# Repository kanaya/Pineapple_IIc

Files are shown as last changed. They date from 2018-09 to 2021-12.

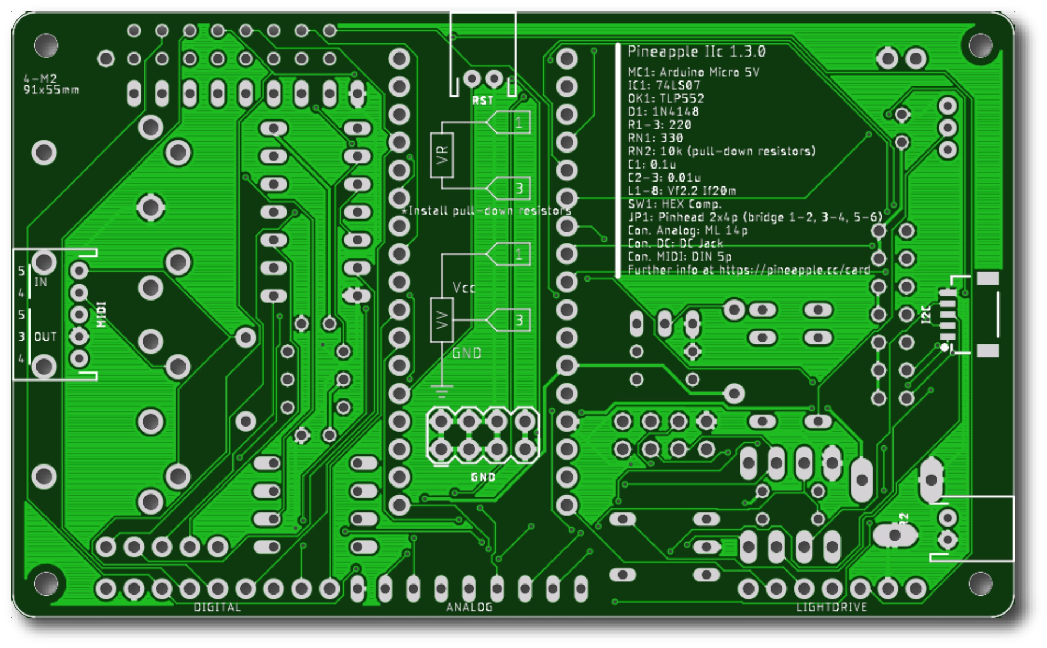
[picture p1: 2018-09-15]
doc/image/Pineapple_IIc_1_3_0_back_shadow_material/4-Pineapple_IIc_1_3_0_back_shadow.png

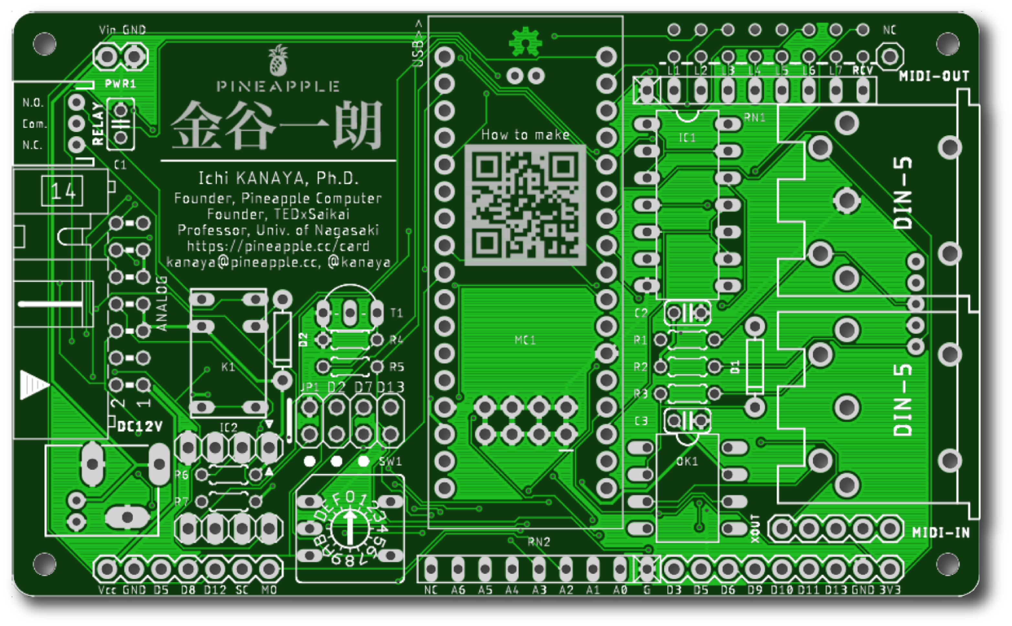
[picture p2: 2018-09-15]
doc/image/Pineapple_IIc_1_3_0_shadow_material/4-Pineapple_IIc_1_3_0_shadow.png

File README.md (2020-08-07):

# Pineapple IIc

Edition 2.0.0 for Pineapple IIc 2.0.0

## Congratulations!

You’ve got the latest version of Pineapple Computer named _Pineapple IIc._ But what is Pineapple Computer? Well, it is a MIDI computer that can convert analog signals to MIDI (digital) signal. Now you may want to ask, I guess, what is it for? The Pineapple Computer is an artist-friendly super-easy-to-use computer! You plug power, sensor, MIDI instrument, and boom! Everything is set up.

## How to set up (Hardware)

### Basics

Install the following components.

| Name | Component | Note |
|---|---|---|
| C1 | 47u | |
| C2 | 10u | |
| C3-6 | 0.1u | |
| D1 | 1N4148 | |
| DC12V | DC Jack | |
| IC1 | 74LS07 | |
| JP2 | Pinheader 1x3p | **Bridge top and mid pins** |
| LED1 | Vf=2.2 If=20m | |
| MC1 | Arduino Micro 5V  | |
| MIDI-OUT | DIN 5p | |
| OK1 | TLP552 | |
| R3-6 | 220 | |
| RN1 | 330 | |
| RN2 | 10k | Using pin sockets is recommended. |
| SV1 | ML 16p | |
| VREG1 | 12V to 5V | |

...To be re-written.

### Non-basic usage

You can drive a relay, I2C devices, and TLC5940 PWM driver by installing some other components on Pineapple IIc. Also you can replace some connectors so that you can use panel mounted connectors and install Pineapple IIc board in a case. For more detail, please read _Extending Pineapple IIc_.

## How to set up (Software)

Install _Pineapple IIc Basic_ sketch to run Pineapple IIc in _Basic_ mode.

## How to play

Connect the following plugs.

* DC---Supply DC 12V to DC Jack connector.
* MIDI---Connect Pineapple IIc's MIDI OUT and your instrument's MIDI IN.
* Sensors---To be written.

## Extending Pineapple IIc

### To use relay

Install the following components as well as _Basic_ components.

| Item | Name | Spec. | # |  Note |
|---|---|---|---|---|
| Transistor  | T1 | 2SC1815 | 1 | |
| Diode | D2 | 1N4148 | 1 | |
| Resistor | R5-6 | 10k | 2 | |
| Relay | K1 | G5V-1 DC5V | 1 | |
| Con. | Relay | PH 3p | 1 | |

Also you need to **bridge 7-8 of JP1.**

### To use I2C

Install the following components as well as _Basic_ components.

| Item | Name | Spec. | # |  Note |
|---|---|---|---|---|
| Signal level converter | IC2  | PCA9517ADP | 1 | Put A-side up, B-side down. |
| Resistor | R7-8 | 6.8k | 2 | |
| Con. | I2C  | SH 5p | 1 | D7 operates at **5V.** |

You need to **un-bridge 1-5, 2-6, 3-7 of JP1.** (D2/SDA and D7 are connected to SW1, and D3PWM/SCL is connected to PWM0 via JP1.)

### To use RST

Install the following components at back side as well as _Basic_ components.

| Item | Name | Spec. | # |  Note |
|---|---|---|---|---|
| Con. | RST (Back) | PH 2p | 1 | |

### To use LIGHTDRIVE

Install the following components as well as _Basic_ components **except for SW1.** Since Arduino's D8 and D12 pins share SW1 connections and LIGHTDRIVE pins, you need to remove SW1.

| Item | Name | Spec. | # |  Note |
|---|---|---|---|---|
| Con. | LIGHTDRIVE | Pinheader 7p | 1 | |

The LIGHTDRIVE pinouts are:

| Lightdrive | Meaning | Arduino Pin |
|---|---|---|
| 1 | Vcc | |
| 2 | GND | |
| 3 | GSCLCK  | D5PWM |
| 4 | BLANK | D8 |
| 5 | XLAT | D12 |
| 6 | SCLCK | SCLK |
| 7 | SIN | MOSI |

### To use extra GND pins

Install the following components at back side as well as _Basic_ components.

| Item | Name | Spec. | # |  Note |
|---|---|---|---|---|
| Con. | GND (back) | Pinheader/socket 2x3p | 1 | |

### To use panel-mounted MIDI connector

Install the following components at back side as well as _Basic_ components.

| Item | Name | Spec. | # |  Note |
|---|---|---|---|---|
| Con. | MIDI (back) | PH 5p | 1 | |

### To use panel-mounted DC Jack

Install one of the following components as well as _Basic_ components.

| Item | Name | Spec. | # |  Note |
|---|---|---|---|---|
| Con. | PWR1 | Pinheader 2p | 1 | |
| Con. | PWR2 (back) | PH 2p | 1 | |

### To use XOUT

XOUT is designed for extra MIDI OUT capability. It is a direct output of Open Collector so that you may want to install 220-ohm resistor for use as MIDI OUT.

Install the following components as well as _Basic_ components.

| Item | Name | Spec. | # |  Note |
|---|---|---|---|---|
| Con. | XOUT | Pinheader 5p | 1 | |

### To use DIGITAL extension

You can hook L1-L7 driver pins by using DIGITAL pins. It also provides +3.3V DC.

Install the following components as well as _Basic_ components.

| Item | Name | Spec. | # |  Note |
|---|---|---|---|---|
| Con. | DIGITL | Pinheader 9p | 1 | |

### To stack multiple cards

To stack multiple cards, you can do one of the following options.

* Use spacer. _Pineapple IIc_ has four M2 holes at each corners ((3, 3), (88, 3) (88, 52), (3, 52) mm).
* Use Pinheaders of Vcc (bottom left), 3V3 (bottom right), _Pogo_ (top right), Vcc (top left) and perhaps GND (next to the Vcc at top left).

## Technical notes

### Arduino Pinout

| Arduino Micro | Signal | JP1 |
|---|---|---|
| RX | MIDI IN | |
| TX | MIDI OUT | |
| D2/SDA | SW0/SDA | 3-4, open to use I2C |
| D3PWM/SCL | PWM0/SCL | |
| D4/A6 | A6 | |
| D5PWM | PWM1 | |
| D6PWM/A7 | PWM2 | |
| D7 | SW1 | 5-6, open to use D7 independently |
| D8/A8 | SW2 | |
| D9PWM/A9 | PWM3 | |
| D10PWM/A10 | PWM4 | |
| D11PWM | PWM5 | |
| D12/A11 | SW3 | |
| D13PWM | PWM6/Relay | 7-8, close to use relay |
| A0-5 | A0-5 | |

### JP1 Pinout

| JP1 | Signal | JP1 | Signal |
|-----|---|-----|---|
| 1 | Level Converter Enable | 2 | GND |
| 3 | D2SDA (SW0/SDA) | 4 | SW0 |
| 5 | D7 (SW1) | 6 | SW1 |
| 7 | D13PWM (PWM6/Relay) | 8 | Relay  |

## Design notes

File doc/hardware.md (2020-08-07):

# Pineapple IIc

_Edition 2.0.1 for Pineapple IIc version 2.0.1-Alpha._

Pineapple IIc is an artist-friendly computer that can convert analog voltage to MIDI signal.

## Overview

Pineapple IIc can take up to 4 analog inputs (0-5V or 0-50mA) and converts them to MIDI signals. An edge of the analog signal (e.g. 0V to 0.1V or 0 to 1mA) causes MIDI Note On signal. Continuous change of the input voltage causes MIDI Control Change, and drop to 0V (or 0mA) causes MIDI Note Off.

Up to 4 analog sensors can be attached to Pineapple IIc. The sensor can be **(1) voltage mode:** analog voltage output (0V when not active), **(2) current mode:** variable resistance (nonconductive when not active).

Table. Sensor Port (16p ML connector)

| Pin | Meaning |
|-----|---|
| S1  | Vcc |
| S2  | GND |
| S3  | GPIO 1 |
| S4  | Analog 1 |
| S5  | Vcc |
| S6  | GND |
| S7  | GPIO 2 |
| S8  | Analog 2 |
| S9  | Vcc |
| S10 | GND |
| S11 | GPIO 3 |
| S12 | Analog 3 |
| S13 | Vcc |
| S14 | GND |
| S15 | GPIO 4 |
| S16 | Analog 4 |

The GPIO 1, 2 and 3 can perform PWM output.

If the pin 3 of MIDI In+ is connected to GND at boot time, Pineapple II switches to _alternative_ mode.

Table. Working mode of Pineapple II

| Aux (m3) | Mode |
|---|---|
| Open | Default mode. Sensor to MIDI Out. |
| GND | Alternative mode. MIDI In to digital out. |

| Pin of Arduino Micro | Meaning |
|---|---|
| D0 | MIDI IN |
| D1 | MIDI OUT |
| D2 | SDA |
| D3 | SCL |
| D4/A6 | Relay |
| D5 | Display 1, SW1 |
| D6/A7 (PWM) | GPIO 1 |
| D7 | Display 2, SW2 |
| D8/A8 | Display 3, SW4 |
| D9/A9 (PWM) | GPIO 2 |
| D10/A10 (PWM) | GPIO 3 |
| D11 | Selector |
| D12/A11 | GPIO 4 |
| D13 | Indicator |
| MOSI | Display 4 |
| MISO | --- |
| SCLK | Display 5 |
| A0 | Analog 1 |
| A1 | Analog 2 |
| A2 | Analog 3 |
| A3 | Analog 4 |
| A4 | SW8 |
| A5 | Thermal sensor, ID |

# Components

| Kind | Symbol | Specification |
|---|---|---|
| Capacitor | C1 | 474 |
| | C2 | 105 |
| | C3 | 104 |
| | C4 | 22u |
| | C5 | 103 |
| | C6 | 103 |
| | C7 | 104 |
| Diode | D1 | 1S3 |
| | D2 | 1S3 |
| | D3 | 1S3 |
| IC | IC1 | 74LS07N |
| Connector | J1 | DC Jack |
| | J2 | DIN 5p |
| | J3 | DIN 5p |
| | J4 | JST PH 2p |
| | J5 | JST PH 3p |
| | J6 | JST PH 5p |
| | J7 | Pinheader 1x5 |
| | J11 | JST SH 4p |
| Jumper | JP1 | Pinheader 2x3 |
| | JP2 | Pinheader 1x3 |
| Relay | K1 | G5V-1 |
| LED | L1 | Any |
| Micro Controller | MC1 | Arduino Micro |
| Optocoupler | OK1 | TLP552 |
| FET | Q11 | BSS138 |
| | Q12 | BSS138 |
| Resistor | R1 | 473 |
| | R2 | 102 |
| | R3 | 221 |
| | R4 | 221 |
| | R5 | 221 |
| | R6 | 221 |
| | R11 | 102 (2012) |
| | R12 | 102 (2012) |
| | R13 | 102 (2012) |
| | R14 | 102 (2012) |
| Resistor Net | RN1 | 10k 4-elements  |
| | RN2 | 4.7k 4-elements |
| Connector ML | SV1 | 16p |
| Transistor | T1 | 2SC1815Y |
| Thermal Sensor | U1 | DS18B20 |
| V. Regulator | V1 | L7805 |

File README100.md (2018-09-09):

# Pineapple IIc 2.0

## Arduino MKR Pinout

| Arduino Micro | Signal | JP1 |
|---|---|---|
| D0~ | PWM0 | |
| D1~ | PWM1 | |
| D2~ | PWM2 | |
| D3~ | PWM3 | |
| D4~ | PWM4 | |
| D5~ | PWM5 | |
| D6~LED | PWM6/Relay | 4-8, close to use relay |
| D7~ | SW1 | 3-7, open to use D7 independently |
| D8~MOSI | SW2 | 1-5, open to use LIGHTDRIVE |
| D9SCK | SW3 | 2-6, open to use LIGHTDRIVE |
| D10~MISO | SW4 | |
| D11SDA | SDA | |
| D12SCL | SCL | |
| D13RX | MIDI IN | |
| D14TX | MIDI OUT | |

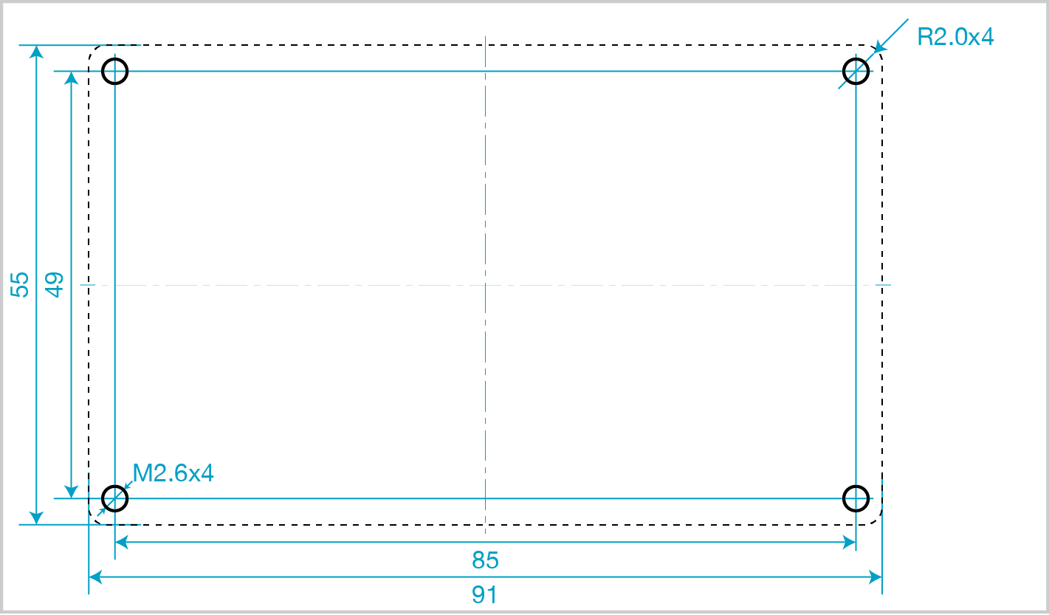
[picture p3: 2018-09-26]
doc/image/Pineapple_IIc_1_5_0_mounting_holes.png

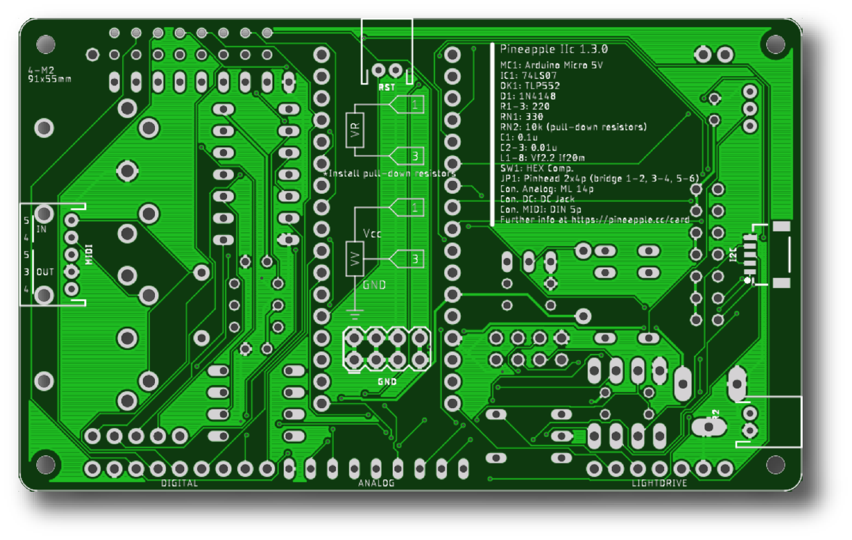
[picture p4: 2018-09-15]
doc/image/Pineapple_IIc_1_3_0_back_half_shadow-QHD.png

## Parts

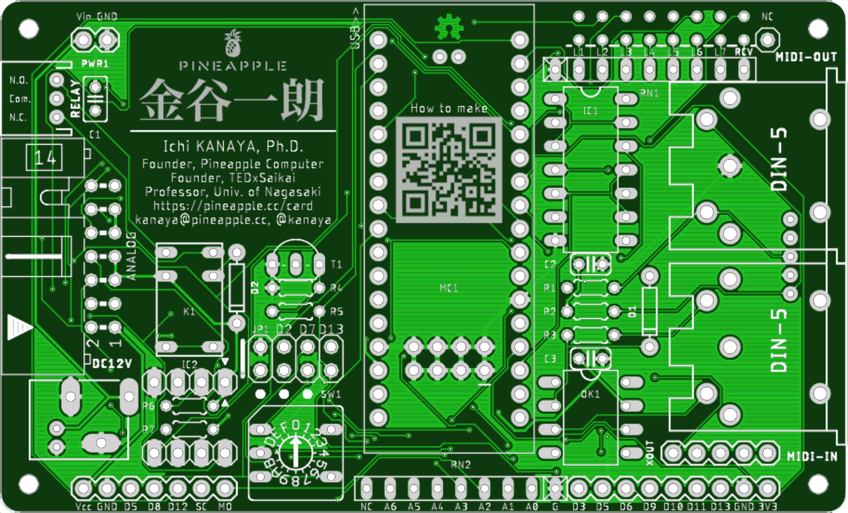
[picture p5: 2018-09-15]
doc/image/Pineapple_IIc_1_3_0_shadow_material/2-Pineapple_IIc_1_3_0.png

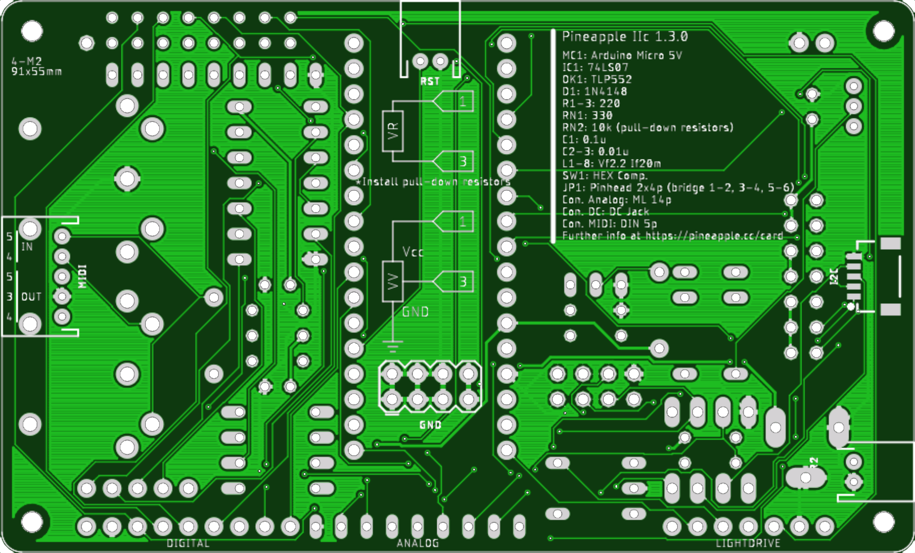
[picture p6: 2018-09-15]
doc/image/Pineapple_IIc_1_3_0_back_shadow_material/2-Pineapple_IIc_1_3_0_back.png

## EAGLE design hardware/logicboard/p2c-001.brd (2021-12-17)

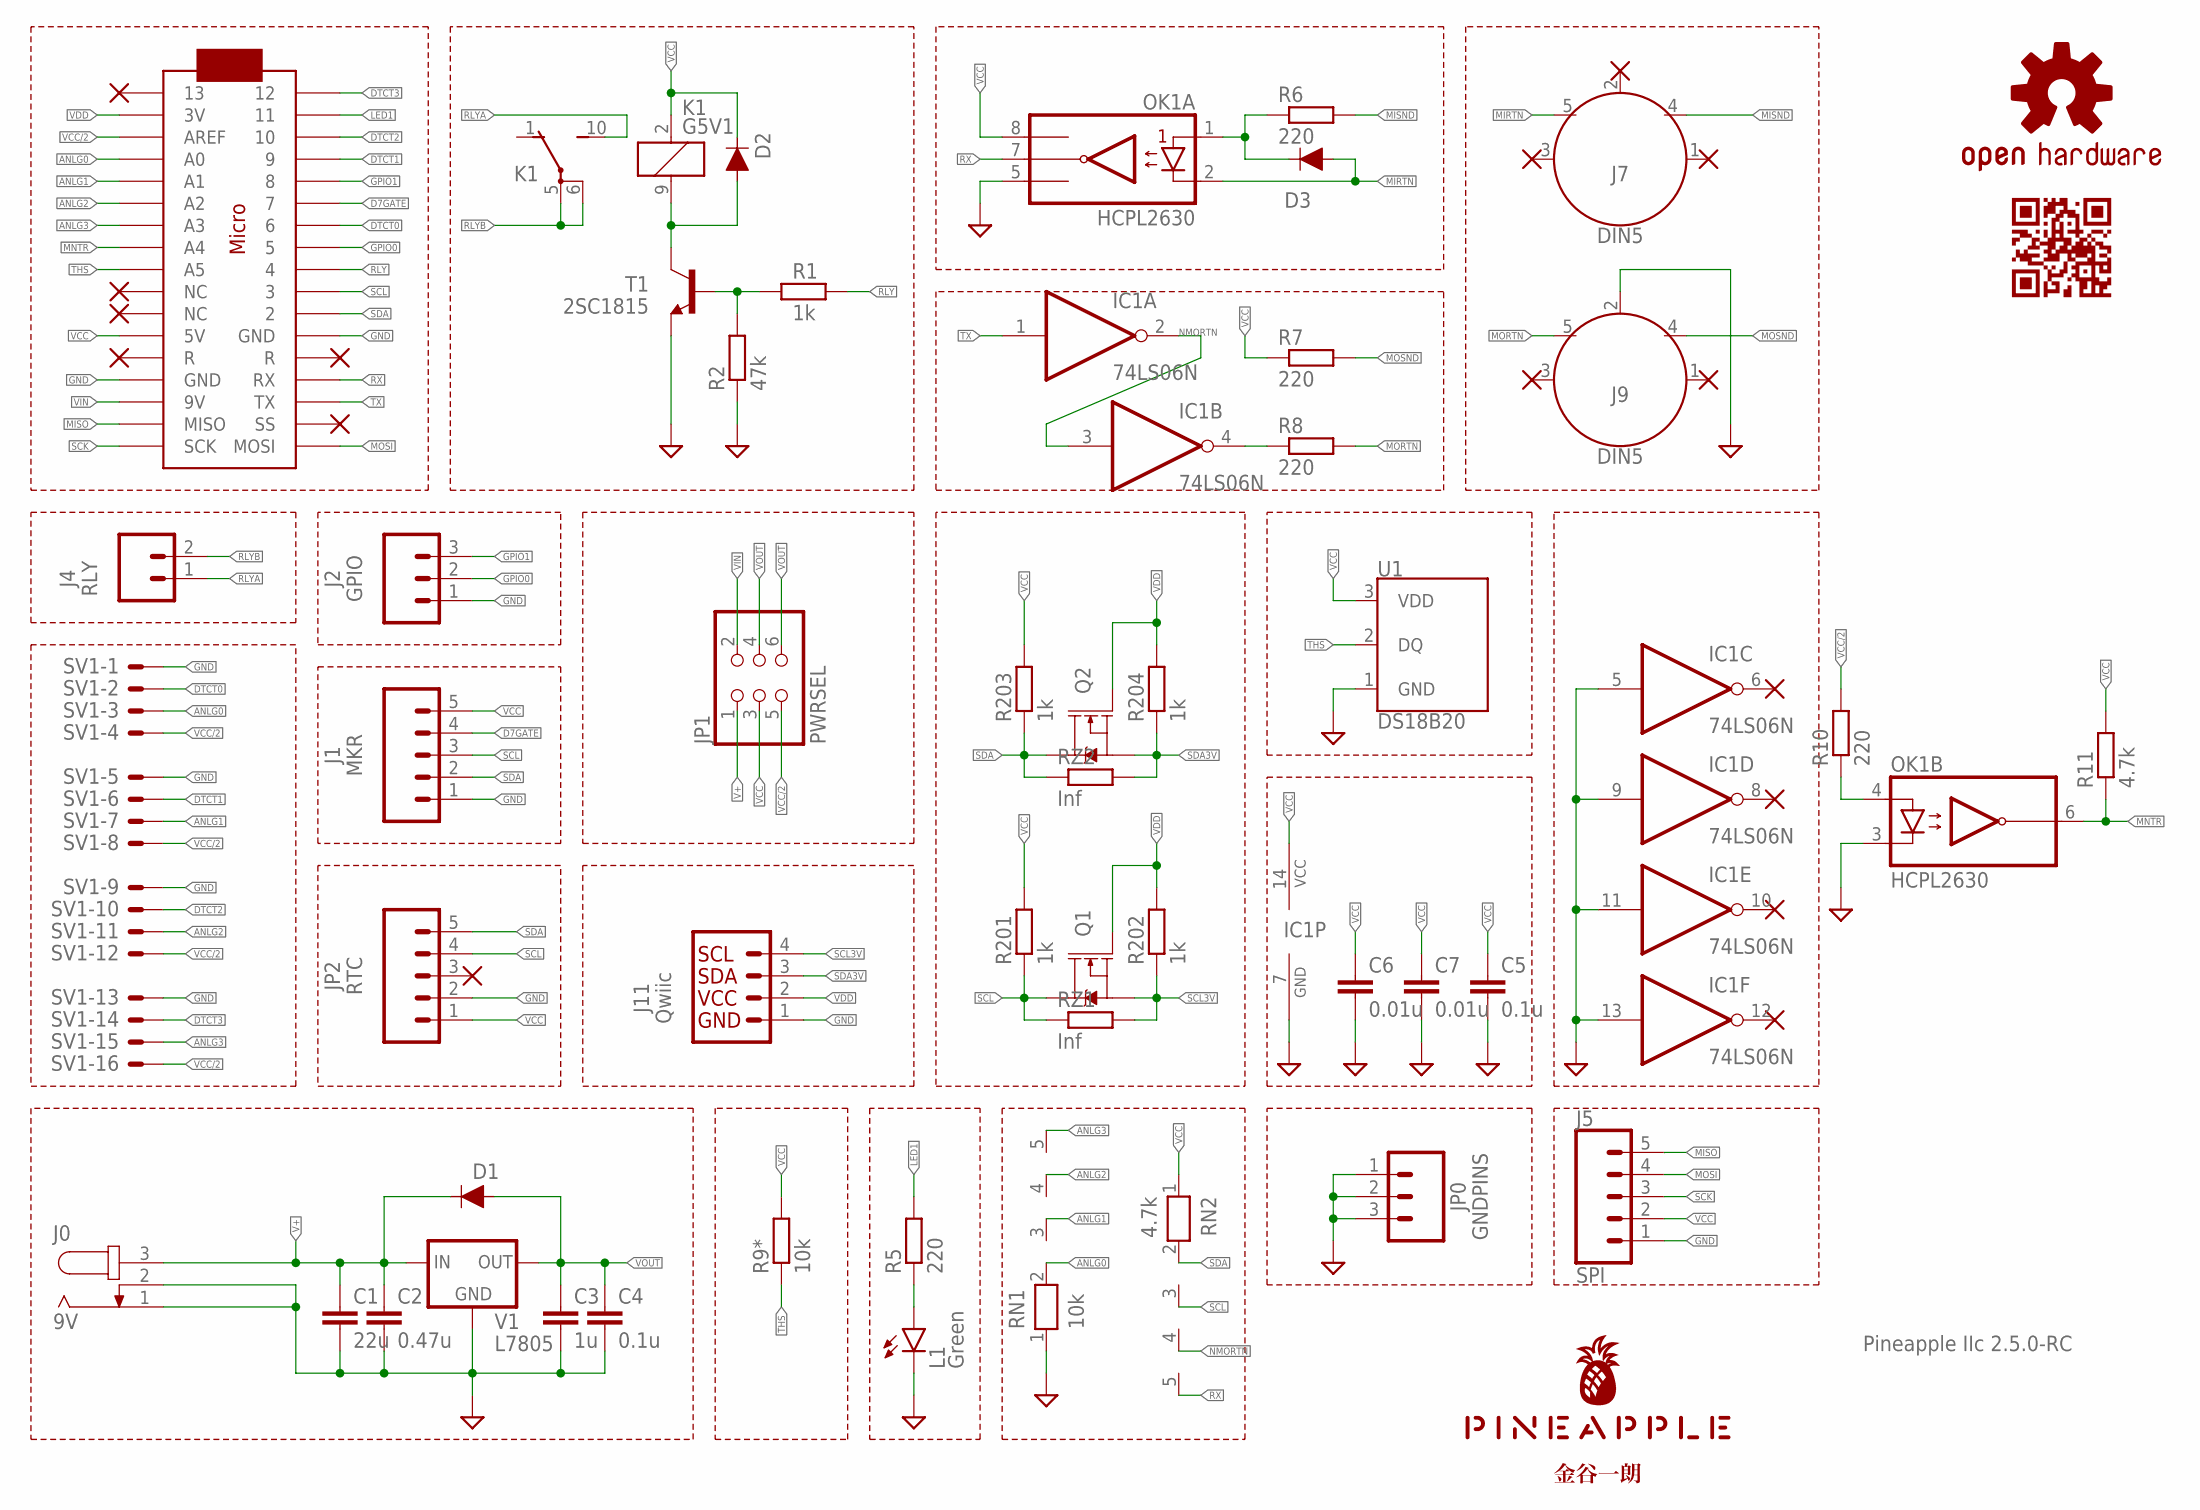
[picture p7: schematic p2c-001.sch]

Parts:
C1: 22u; C025-050X050
C2: 0.47u; C050-024X044
C3: 1u; C050-024X044
C4, C5: 0.1u; C025-024X044
C6, C7: 0.01u; C025-024X044
D1, D2, D3: DIODE-1N4148
IC1: 74LS06N; DIL14
J0: 9V; SPC4077
J1: MKR; JST-5-PTH
J2: GPIO; JST-3-PTH
J4: RLY; JST-2-PTH
J5: SPI; JST-5-PTH-VERT
J7, J9: DIN5; DIN5-RA-PTH
J11: Qwiic; 1X04_1MM_RA
JP0: GNDPINS; 1X03
JP1: PWRSEL; 2X03
JP2: RTC; 1X05
K1: G5V1
L1: Green; LED3MM
LOGO1: OSHW-LOGOS-COPPER; OSHW-LOGO-S_COPPER
OK1: HCPL2630; DIL08
Q1, Q2: 220mA/50V/3.5Ω; SOT23-3
R1: 1k; 0204/5
R2: 47k; 0204/5
R5, R6, R7, R8, R10: 220; 0204/5
R9*: 10k; 0204/5
R11: 4.7k; 0204/5
R201, R202, R203, R204: 1k; R2012
RN1: 10k; RN-5
RN2: 4.7k; RN-5
RZ1, RZ2: Inf; R2012
SV1: ML16LE; ML16L
T1: 2SC1815; TO92-ECB
U1: DS18B20; TO-92-AMMO
U$1: PINEAPPLE450_SILK
U$2: ARDUINOMICRO
U$3: KANAYA768_SILK
U$4: CARDQRCODE450_SILK
V1: L7805; 78XXS

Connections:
ANLG0: RN1.2, SV1.3, U$2.P$31 (A0)
ANLG1: RN1.3, SV1.7, U$2.P$30 (A1)
ANLG2: RN1.4, SV1.11, U$2.P$29 (A2)
ANLG3: RN1.5, SV1.15, U$2.P$28 (A3)
D7GATE: J1.4, U$2.P$6 (7)
DTCT0: SV1.2, U$2.P$7 (6)
DTCT1: SV1.6, U$2.P$4 (9)
DTCT2: SV1.10, U$2.P$3 (10)
DTCT3: SV1.14, U$2.P$1 (12)
GND: C1.2, C2.2, C3.2, C4.2, C5.2, C6.2, C7.2, IC1.5 (I), IC1.7 (GND), IC1.9 (I), IC1.11 (I), IC1.13 (I), J0.1, J0.2, J1.1, J2.1, J5.1, J9.2, J11.1 (GND), JP0.1, JP0.2, JP0.3, JP2.2, L1.K (C), OK1.3 (C2), OK1.5 (GND), R2.1, RN1.1, SV1.1, SV1.5, SV1.9, SV1.13, T1.E, U1.1 (GND), U$2.P$12 (GND), U$2.P$21 (GND), V1.GND
GPIO0: J2.2, U$2.P$8 (5)
GPIO1: J2.3, U$2.P$5 (8)
LED1: R5.2, U$2.P$2 (11)
LED1A: L1.A, R5.1
MIA: D3.C, OK1.1 (A1), R6.1
MIRTN: D3.A, J7.5, OK1.2 (C1)
MISND: J7.4, R6.2
MISO: J5.5, U$2.P$19 (MISO)
MNTR: OK1.6 (VO2), R11.1, U$2.P$27 (A4)
MNTRA: OK1.4 (A2), R10.1
MORTN: J9.5, R8.2
MORTNRAW: IC1.4 (O), R8.1
MOSI: J5.4, U$2.P$17 (MOSI)
MOSND: J9.4, R7.2
NMORTN: IC1.2 (O), IC1.3 (I), RN2.4
RLY: R1.2, U$2.P$9 (4)
RLYA: J4.1, K1.10 (S)
RLYB: J4.2, K1.5, K1.6
RLYC: D2.A, K1.9 (2), T1.C
RLYQ: R1.1, R2.2, T1.B
RX: OK1.7 (VO1), RN2.5, U$2.P$14 (RX)
SCK: J5.3, U$2.P$18 (SCK)
SCL: J1.3, JP2.4, Q1.3 (D), R201.1, RN2.3, RZ1.1, U$2.P$10 (3)
SCL3V: J11.4 (SCL), Q1.2 (S), R202.1, RZ1.2
SDA: J1.2, JP2.5, Q2.3 (D), R203.1, RN2.2, RZ2.1, U$2.P$11 (2)
SDA3V: J11.3 (SDA), Q2.2 (S), R204.1, RZ2.2
THS: R9*.1, U1.2 (DQ), U$2.P$26 (A5)
TX: IC1.1 (I), U$2.P$15 (TX)
V+: C1.1, C2.1, D1.C, J0.3, JP1.1, V1.IN
VCC: C5.1, C6.1, C7.1, D2.C, IC1.14 (VCC), J1.5, J5.2, JP1.3, JP2.1, K1.2 (1), OK1.8 (VCC), R7.1, R9*.2, R11.2, R201.2, R203.2, RN2.1, U1.3 (VDD), U$2.P$23 (5V)
VCC/2: JP1.5, R10.2, SV1.4, SV1.8, SV1.12, SV1.16, U$2.P$32 (AREF)
VDD: J11.2 (VCC), Q1.1 (G), Q2.1 (G), R202.2, R204.2, U$2.P$33 (3V)
VIN: JP1.2, U$2.P$20 (9V)
VOUT: C3.1, C4.1, D1.A, JP1.4, JP1.6, V1.OUT

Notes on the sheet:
Pineapple IIc 2.5.0-RC

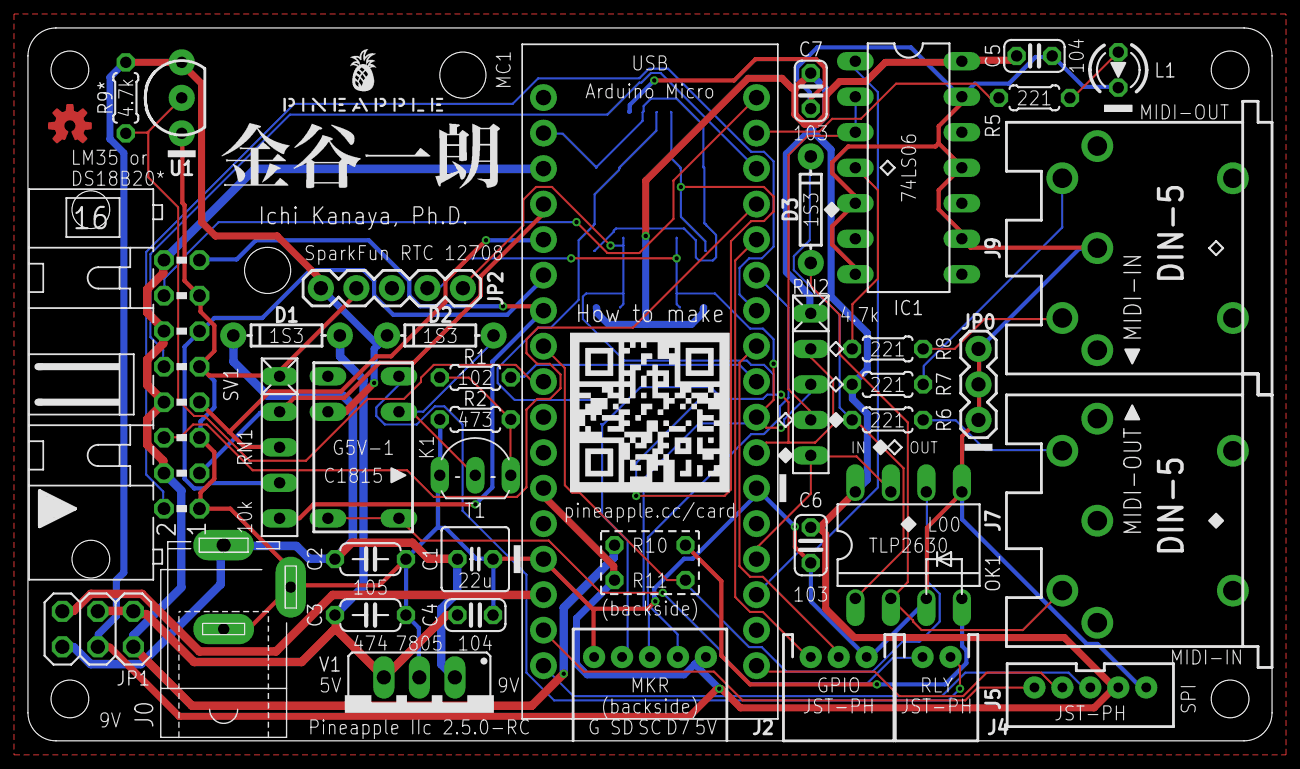
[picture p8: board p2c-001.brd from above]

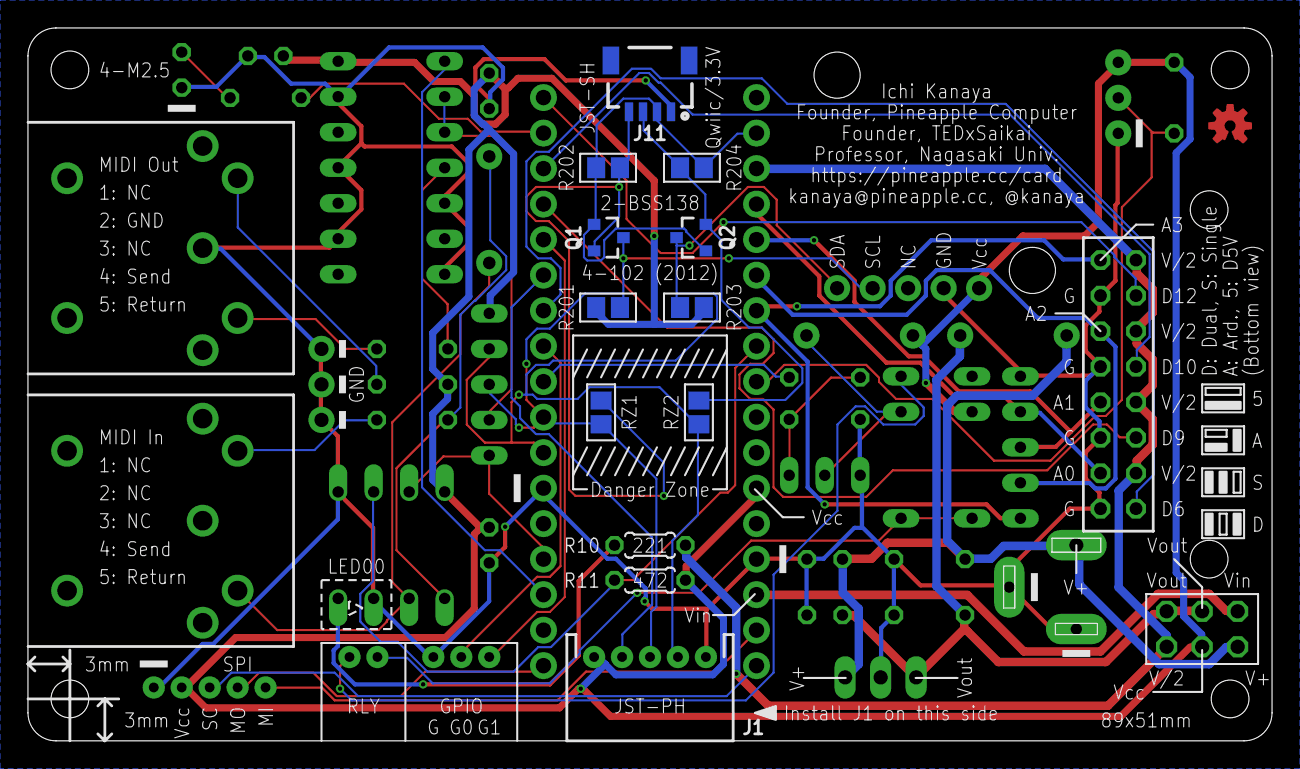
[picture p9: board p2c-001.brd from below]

Board: 2 copper layers, 89.0 x 51.0 mm, 55 parts (12 on the bottom side), 44 nets.

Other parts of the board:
U$5, U$6: STAND-OFF

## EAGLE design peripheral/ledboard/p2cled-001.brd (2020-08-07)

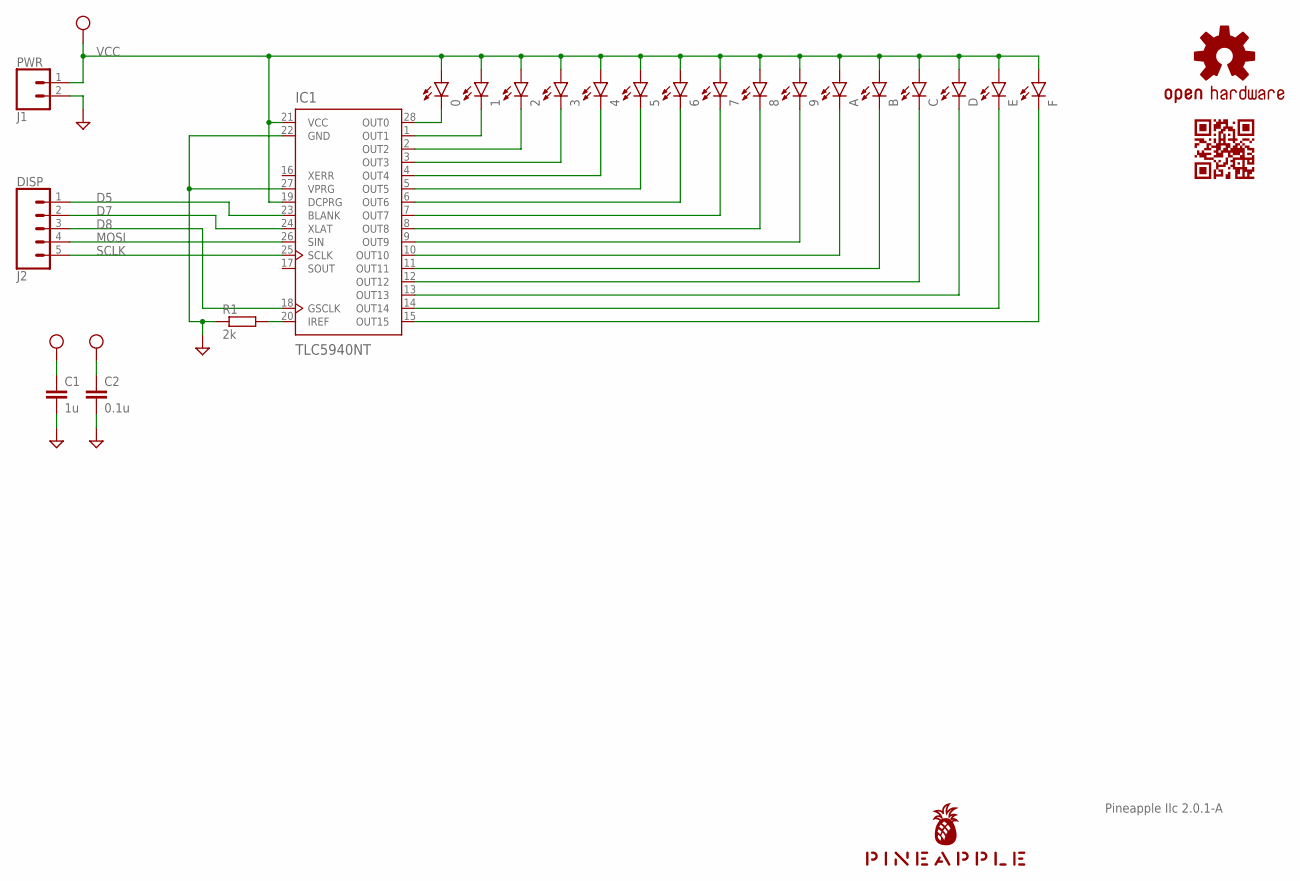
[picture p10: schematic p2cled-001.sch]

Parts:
0, 1, 2, 3, 4, 5, 6, 7, 8, 9: LEDB152; Q62902-B152
A: LEDB152; Q62902-B152
B: LEDB152; Q62902-B152
C: LEDB152; Q62902-B152
C1: 1u; C025-024X044
C2: 0.1u; C025-024X044
D: LEDB152; Q62902-B152
E: LEDB152; Q62902-B152
F: LEDB152; Q62902-B152
IC1: TLC5940NT; DIL28-3
J1: PWR; JST-2-PTH
J2: DISP; JST-5-PTH
LOGO1: OSHW-LOGOS-COPPER; OSHW-LOGO-S_COPPER
R1: 2k; 0204/5
U$1: PINEAPPLE450_SILK
U$4: CARDQRCODE450_SILK

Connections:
D5: IC1.23 (BLANK), J2.1
D7: IC1.24 (XLAT), J2.2
D8: IC1.18 (GSCLK), J2.3
GND: C1.2, C2.2, IC1.22 (GND), IC1.27 (VPRG), J1.2, R1.1
MOSI: IC1.26 (SIN), J2.4
unnamed: 0.K (C), IC1.28 (OUT0)
unnamed: 1.K (C), IC1.1 (OUT1)
unnamed: 2.K (C), IC1.2 (OUT2)
unnamed: 3.K (C), IC1.3 (OUT3)
unnamed: 4.K (C), IC1.4 (OUT4)
unnamed: 5.K (C), IC1.5 (OUT5)
unnamed: 6.K (C), IC1.6 (OUT6)
unnamed: 7.K (C), IC1.7 (OUT7)
unnamed: 8.K (C), IC1.8 (OUT8)
unnamed: 9.K (C), IC1.9 (OUT9)
unnamed: A.K (C), IC1.10 (OUT10)
unnamed: B.K (C), IC1.11 (OUT11)
unnamed: C.K (C), IC1.12 (OUT12)
unnamed: D.K (C), IC1.13 (OUT13)
unnamed: E.K (C), IC1.14 (OUT14)
unnamed: F.K (C), IC1.15 (OUT15)
unnamed: IC1.20 (IREF), R1.2
SCLK: IC1.25 (SCLK), J2.5
VCC: 0.A, 1.A, 2.A, 3.A, 4.A, 5.A, 6.A, 7.A, 8.A, 9.A, A.A, B.A, C.A, C1.1, C2.1, D.A, E.A, F.A, IC1.19 (DCPRG), IC1.21 (VCC), J1.1

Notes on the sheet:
Pineapple IIc 2.0.1-A

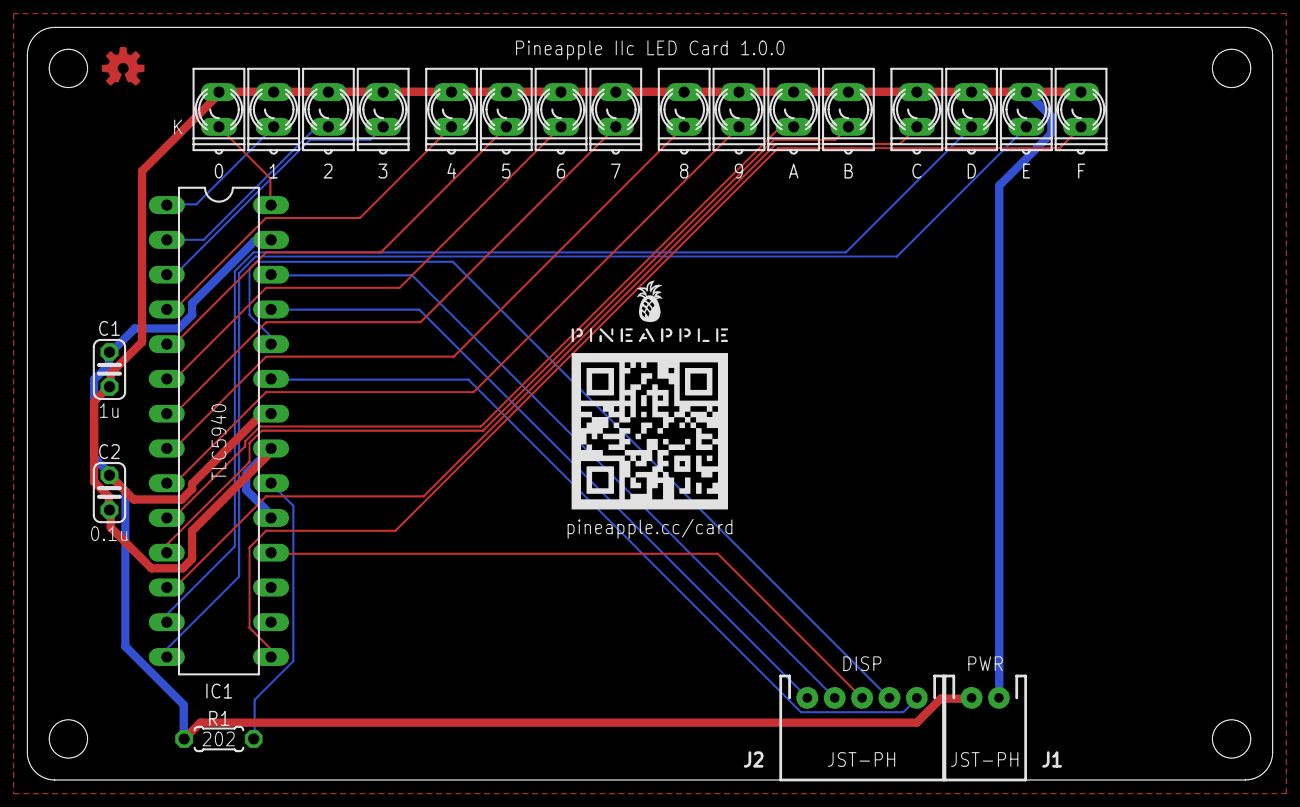
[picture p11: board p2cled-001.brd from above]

Board: 2 copper layers, 91.0 x 55.0 mm, 25 parts (0 on the bottom side), 24 nets.

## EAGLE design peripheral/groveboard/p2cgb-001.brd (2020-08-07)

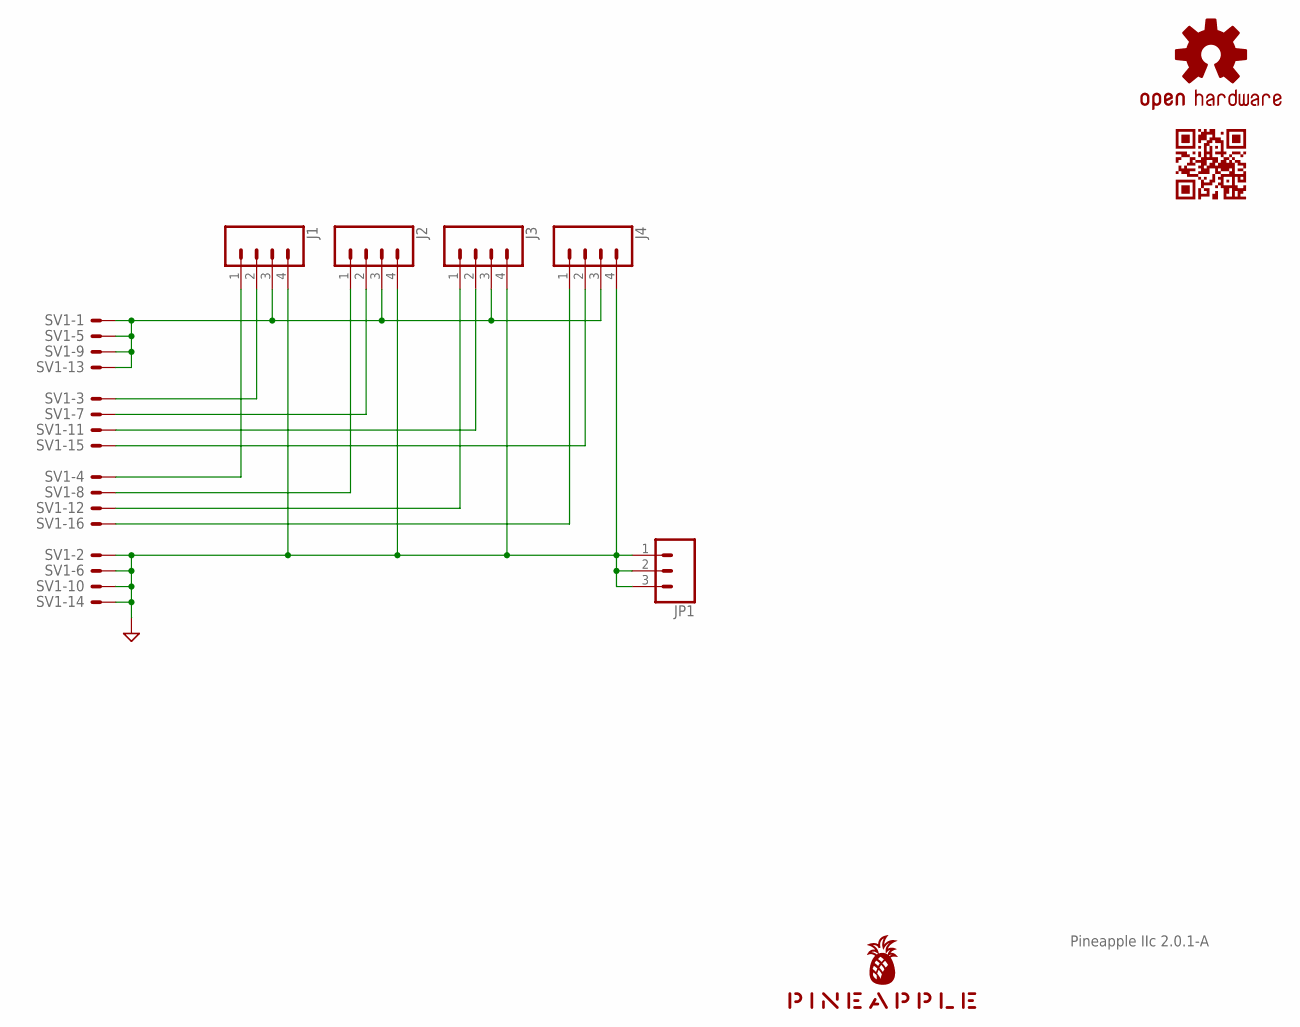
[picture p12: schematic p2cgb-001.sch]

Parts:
J1, J2, J3, J4: CONN_04JST-PTH; JST-4-PTH
JP1: CONN_03; 1X03
LOGO1: OSHW-LOGOS-COPPER; OSHW-LOGO-S_COPPER
SV1: ML16LE; ML16L
U$1: PINEAPPLE450_SILK
U$4: CARDQRCODE450_SILK

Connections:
GND: J1.4, J2.4, J3.4, J4.4, JP1.1, JP1.2, JP1.3, SV1.2, SV1.6, SV1.10, SV1.14
unnamed: J1.1, SV1.4
unnamed: J2.1, SV1.8
unnamed: J3.1, SV1.12
unnamed: J4.1, SV1.16
unnamed: J1.2, SV1.3
unnamed: J2.2, SV1.7
unnamed: J3.2, SV1.11
unnamed: J4.2, SV1.15
VCC: J1.3, J2.3, J3.3, J4.3, SV1.1, SV1.5, SV1.9, SV1.13

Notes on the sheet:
Pineapple IIc 2.0.1-A

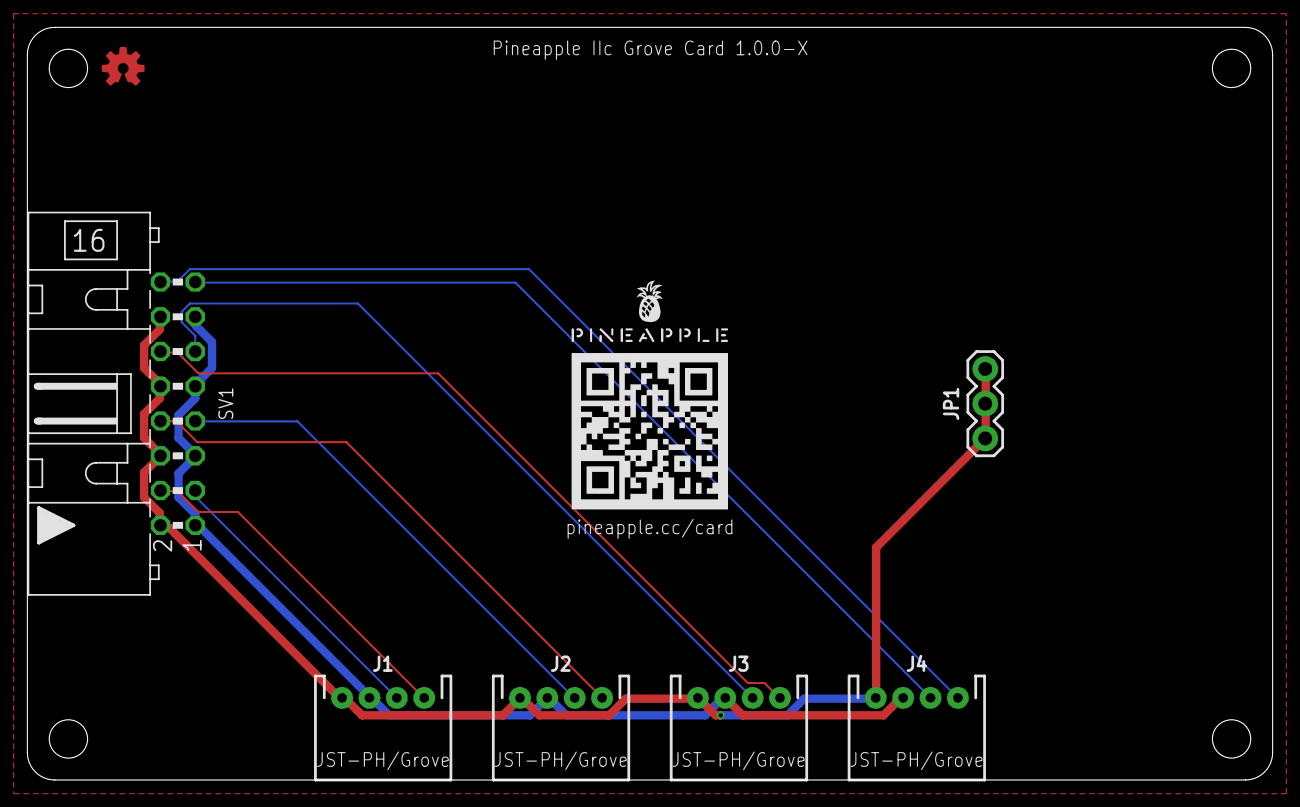
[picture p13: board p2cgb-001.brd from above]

Board: 2 copper layers, 91.0 x 55.0 mm, 9 parts (0 on the bottom side), 10 nets.

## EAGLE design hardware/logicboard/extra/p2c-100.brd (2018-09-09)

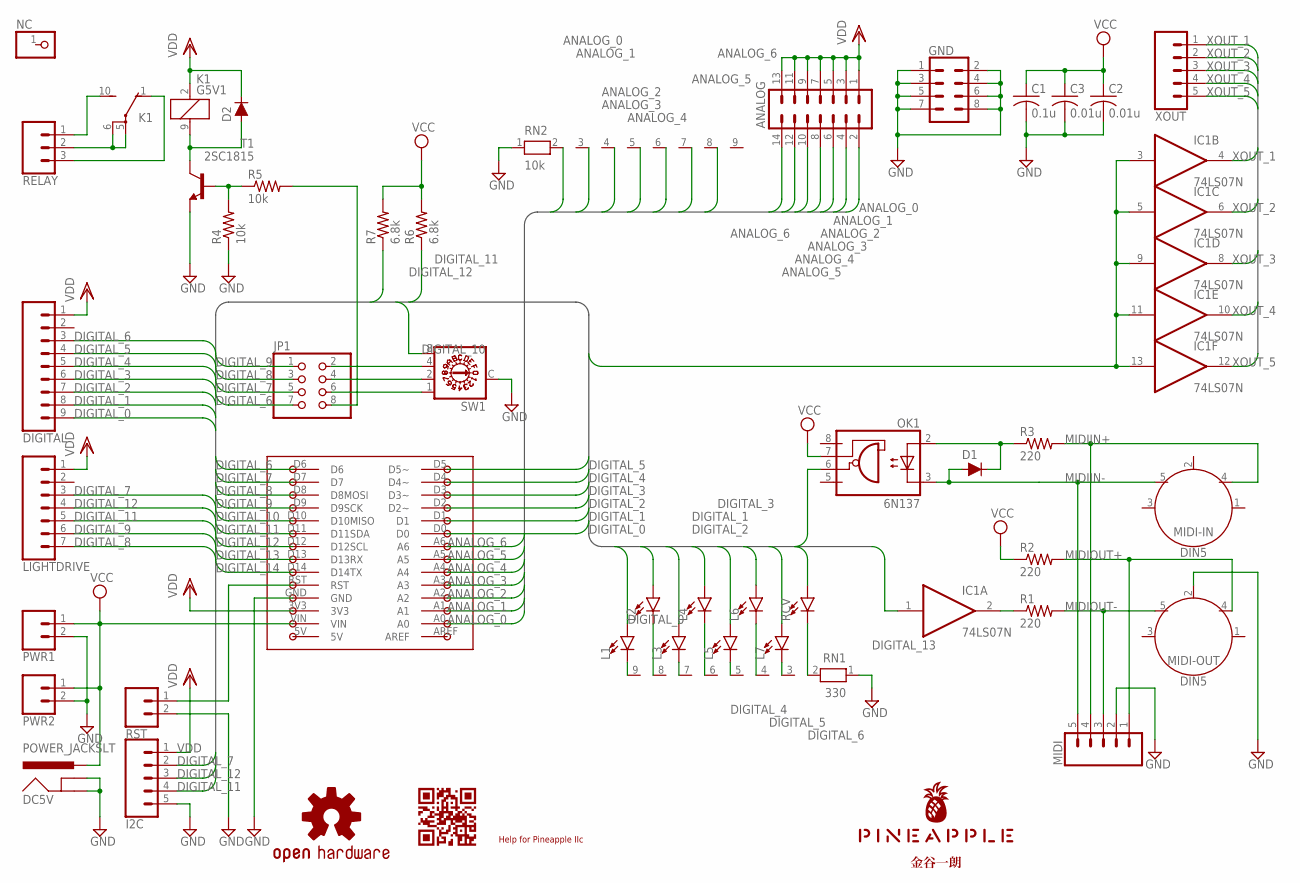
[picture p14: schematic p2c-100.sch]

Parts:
ANALOG: ML14L
C1: 0.1u; C025-025X050
C2, C3: 0.01u; C025-024X044
D1, D2: DIODE-1N4148
DC5V: POWER_JACKSLT; POWER_JACK_SLOT
DIGITAL: CONN_09; 1X09
GND: CONN_04X2; 2X4
I2C: CONN_05SMD2; 1X05_1MM_RA
IC1: 74LS07N; DIL14
JP1: PINHD-2X4; 2X04
K1: G5V1
L1, L2, L3, L4, L5, L6, L7: LED-3MM-NO_SILK; LED_3MM-NS
LIGHTDRIVE: CONN_07; 1X07
LOGO1: OSHW-LOGOS-COPPER; OSHW-LOGO-S_COPPER
MIDI: CONN_05JST; JST-5-PTH
MIDI-IN: DIN5; DIN5-RA-PTH
MIDI-OUT: DIN5; DIN5-RA-PTH
NC: PINHD-1X1; 1X01
OK1: 6N137; DIL08
PWR1: CONN_02; 1X02
PWR2: CONN_02JST-PTH-2; JST-2-PTH
R1, R2, R3: 220; 0204/5
R4, R5: 10k; 0204/5
R6, R7: 6.8k; 0204/5
RCV: LED-3MM-NO_SILK; LED_3MM-NS
RELAY: CONN_03JST-PTH; JST-3-PTH
RN1: 330; RN-9
RN2: 10k; RN-9
RST: CONN_02JST-PTH-2; JST-2-PTH
SW1: A1353HEX
T1: 2SC1815; TO92-ECB
U1: MKR1000
U$1: PINEAPPLE450_SILK
U$3: KANAYA768_SILK
U$4: CARDQRCODE450_SILK
U$5: HELP_P2C
XOUT: CONN_05; 1X05

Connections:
ANALOG_0: ANALOG.2, RN2.2, U1.A0
ANALOG_1: ANALOG.4, RN2.3, U1.A1
ANALOG_2: ANALOG.6, RN2.4, U1.A2
ANALOG_3: ANALOG.8, RN2.5, U1.A3
ANALOG_4: ANALOG.10, RN2.6, U1.A4
ANALOG_5: ANALOG.12, RN2.7, U1.A5
ANALOG_6: ANALOG.14, RN2.8, U1.A6
DIGITAL_0: DIGITAL.9, L1.A, U1.D0
DIGITAL_1: DIGITAL.8, L2.A, U1.D1
DIGITAL_2: DIGITAL.7, L3.A, U1.D2 (D2~)
DIGITAL_3: DIGITAL.6, L4.A, U1.D3 (D3~)
DIGITAL_4: DIGITAL.5, L5.A, U1.D4 (D4~)
DIGITAL_5: DIGITAL.4, L6.A, U1.D5 (D5~)
DIGITAL_6: DIGITAL.3, JP1.7, L7.A, U1.D6
DIGITAL_7: I2C.2, JP1.5, LIGHTDRIVE.3, U1.D7
DIGITAL_8: JP1.3, LIGHTDRIVE.7, U1.D8 (D8MOSI)
DIGITAL_9: JP1.1, LIGHTDRIVE.6, U1.D9 (D9SCK)
DIGITAL_10: SW1.8, U1.D10 (D10MISO)
DIGITAL_11: I2C.4, LIGHTDRIVE.5, R6.1, U1.D11 (D11SDA)
DIGITAL_12: I2C.3, LIGHTDRIVE.4, R7.1, U1.D12 (D12SCL)
DIGITAL_13: OK1.6 (VO), RCV.A, U1.D13 (D13RX)
DIGITAL_14: IC1.1 (I), IC1.3 (I), IC1.5 (I), IC1.9 (I), IC1.11 (I), IC1.13 (I), U1.D14 (D14TX)
GND: C1.2, C2.2, C3.2, DC5V.GND@1 (GNDBREAK), DC5V.GND@2 (GND), GND.1, GND.2, GND.3, GND.4, GND.5, GND.6, GND.7, GND.8, I2C.5, IC1.7 (GND), MIDI.2, MIDI-OUT.2, PWR1.2, PWR2.2, R4.1, RN1.1, RN2.1, RST.2, SW1.C, T1.E, U1.GND
MIDIIN+: MIDI.4, MIDI-IN.4, R3.2
MIDIIN-: D1.A, MIDI.5, MIDI-IN.5, OK1.3 (C)
MIDIINA: D1.C, OK1.2 (A), R3.1
MIDIOUT+: MIDI.1, MIDI-OUT.4, R2.2
MIDIOUT-: MIDI.3, MIDI-OUT.5, R1.2
MIDIOUTC: IC1.2 (O), R1.1
unnamed: L1.K (C), RN1.9
unnamed: RST.1, U1.RST
unnamed: JP1.8, R5.2
unnamed: JP1.6, SW1.1
unnamed: JP1.4, SW1.2
unnamed: JP1.2, SW1.4
unnamed: L2.K (C), RN1.8
unnamed: L3.K (C), RN1.7
unnamed: L4.K (C), RN1.6
unnamed: L5.K (C), RN1.5
unnamed: L6.K (C), RN1.4
unnamed: L7.K (C), RN1.3
unnamed: RCV.K (C), RN1.2
RELAYCOM: K1.5, K1.6, RELAY.2
RELAYDRIVE: R4.2, R5.1, T1.B
RELAYNC: K1.1 (O), RELAY.3
RELAYNO: K1.10 (S), RELAY.1
RELAYTR: D2.A, K1.9 (2), T1.C
VCC: C1.1, C2.1, C3.1, DC5V.PWR, IC1.14 (VCC), OK1.7 (VE), PWR1.1, PWR2.1, R2.1, R6.2, R7.2, U1.VIN
VDD: ANALOG.1, ANALOG.3, ANALOG.5, ANALOG.7, ANALOG.9, ANALOG.11, ANALOG.13, D2.C, DIGITAL.1, I2C.1, K1.2 (1), LIGHTDRIVE.1, U1.3V3
XOUT_1: IC1.4 (O), XOUT.1
XOUT_2: IC1.6 (O), XOUT.2
XOUT_3: IC1.8 (O), XOUT.3
XOUT_4: IC1.10 (O), XOUT.4
XOUT_5: IC1.12 (O), XOUT.5

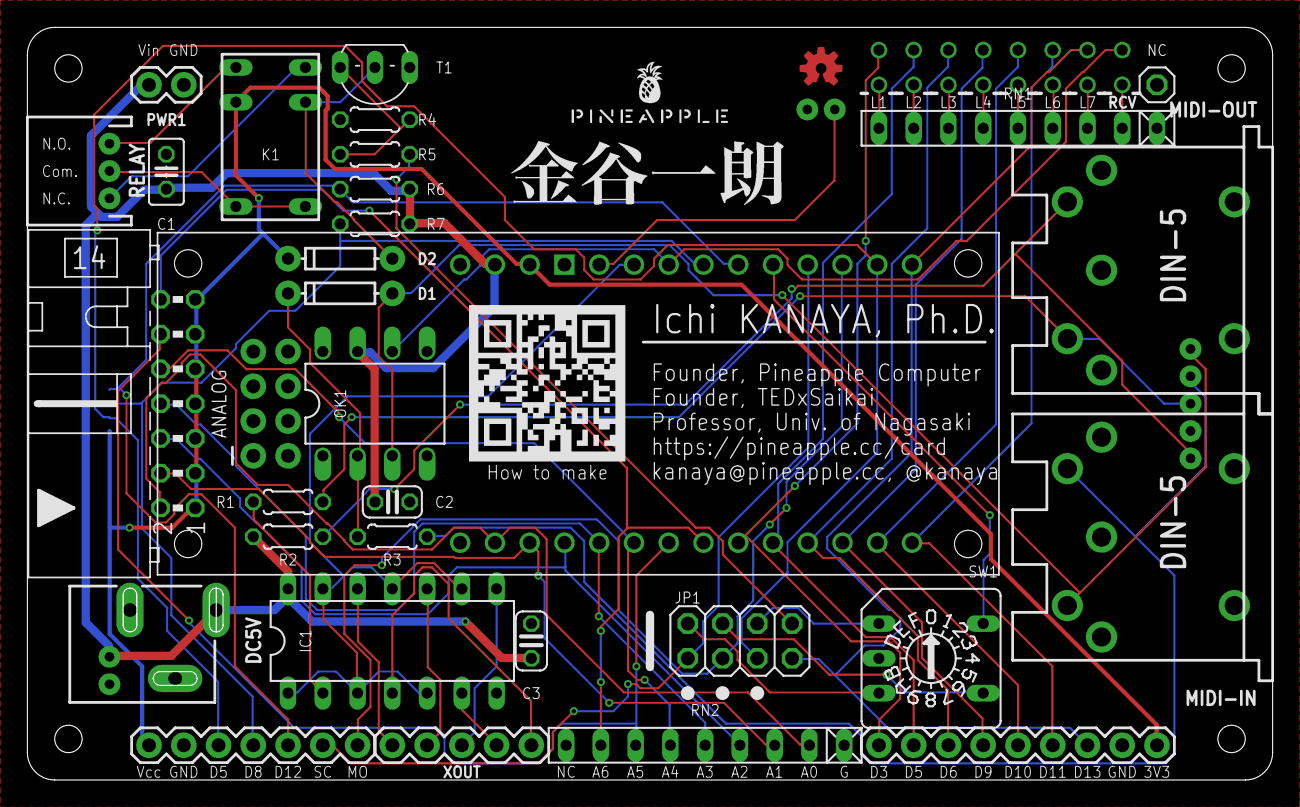
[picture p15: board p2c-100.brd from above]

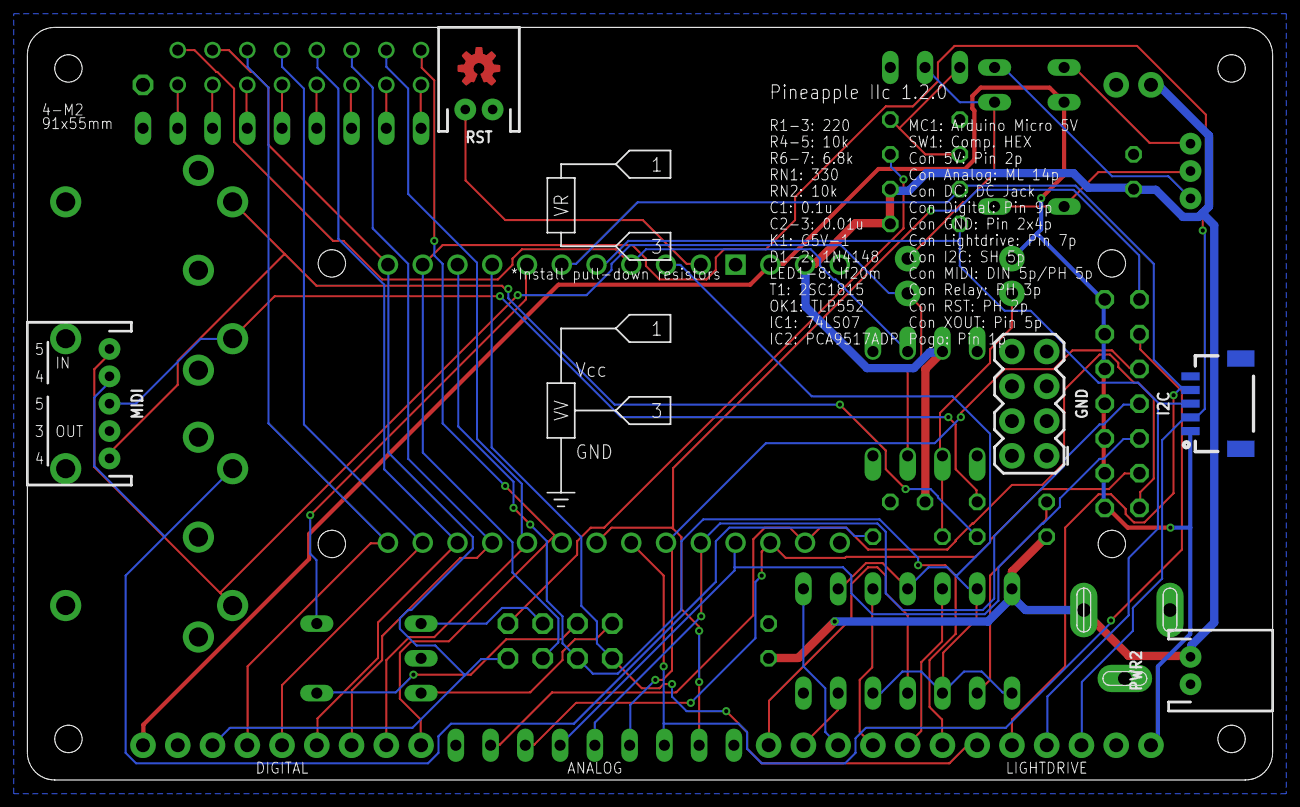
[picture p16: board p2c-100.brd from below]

Board: 2 copper layers, 91.0 x 55.0 mm, 49 parts (6 on the bottom side), 54 nets.

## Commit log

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2018-08-23 Added RST (reset) connector.
    [p2c-001.brd, p2c-001.sch]
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2018-08-23 I2C level converter (PCA9517ADP) is added.
    [p2c-001.brd, p2c-001.sch]
2018-08-23 CUT2ENBLI2C (cut to enable I2C) pins.
    [p2c-001.brd, p2c-001.sch]
2018-08-23 Short pins for enabling I2C.
    [p2c-001.brd, p2c-001.sch]
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2018-08-23 Minor change of silk pattern.
    [p2c-001.brd, p2c-001.sch]
2018-08-23 Moved component list to the back side.
    [p2c-001.brd]
2018-08-23 Alternative DC and MIDI connectors.
    [p2c-001.brd, p2c-001.sch]
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2018-08-23 Drill hole for Arduino Micro.
    [p2c-001.brd]
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2018-08-23 Added "How to make".
    [p2c-001.brd]
2018-08-23 Added bar mark on the back side.
    [p2c-001.brd]
2018-08-24 Now the name is printed by silk.
    [p2c-001.brd, p2c-001.sch]
2018-08-24 Moved OSHW logo up.
    [p2c-001.brd]
2018-08-24 Changed OSHW logo from silk to copper.
    [p2c-001.brd, p2c-001.sch]
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2018-08-24 Changed DC jack and alternative connectors.
    [p2c-001.brd, p2c-001.sch]
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2018-08-24 Changed pinheaders to Sparkfan's ones.
    [p2c-001.brd, p2c-001.sch]
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2018-08-24 Pull-down resistor pattern now allows installing analog-input socket.
    [p2c-001.brd, p2c-001.sch]
2018-08-25 Position of analog input/pull-down.
    [p2c-001.brd, p2c-001.sch]
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2018-08-25 Fixed error.
    [p2c-001.brd]
2018-08-25 New logo, new QR code.
    [p2c-001.brd, p2c-001.sch]
2018-08-25 Some silk fonts are changed from 1.0mm to 0.8mm.
    [p2c-001.brd]
2018-08-25 More changes to silk pattern.
    [p2c-001.brd]
2018-08-25 Moved silk pattern of the back side.
    [p2c-001.brd]
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2018-08-25 Changed backside silk pattern.
    [p2c-001.brd]
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2018-08-25 Added backside silk pattern.
    [p2c-001.brd]
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2018-08-26 Signal lines now has 6-mil wide, and power lines has 12-mil wide.
    [p2c-001.brd, p2c-001.sch]
2018-08-26 Now has Lightdrive and MKR1000-compatible I2C connector.
    [p2c-001.brd, p2c-001.sch]
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2018-08-26 Fixed backside notes.
    [p2c-001.brd, p2c-001.sch]
2018-08-26 GND pattern now has 100mil clearance. Moved several pinheaders.
    [p2c-001.brd]
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2018-08-26 Fixed note of the back side.
    [p2c-001.brd]
2018-08-26 Reversed Digital pin.
    [p2c-001.brd, p2c-001.sch]
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2018-08-26 Swapped R6 and R7.
    [p2c-001.brd]
2018-08-26 Swapped Vcc and GND of LD.
    [p2c-001.brd, p2c-001.sch]
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2018-08-30 Moved PWR pinheaders and Pogo pinhead. Added PWR2 PH connector. Changed Lightdrive pinout.
    [p2c-001.brd, p2c-001.sch]
2018-09-01 Silk (3.3V -> 3V3).
    [p2c-001.brd]
2018-09-03 Changed DC jack to small-pin type.
    [p2c-001.brd, p2c-001.sch]
2018-09-03 Changed Vin and Vcc line widths to 24mil.
    [p2c-001.brd]
2018-09-04 Started design of DX board.
    [p2c-002-dx.brd, p2c-002-dx.sch]
2018-09-04 Removed unnecessary parts from DX board.
    [p2c-002-dx.brd, p2c-002-dx.sch]
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2018-09-06 Added "How to use."
    [p2c-001.brd, p2c-001.sch]
2018-09-08 Fixed QR code.
    [p2c-001.brd, p2c-001.sch, p2c-002-dx.brd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]
2018-09-08 Slightly moved external pins.
    [p2c-001.brd]
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2018-09-08 Moved extra files to extra dir.
    [p2c-000-plain.brd, p2c-000-plain.sch, p2c-002-dx.brd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]
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2018-09-09 Now power lines are also autorouted.
    [p2c-001.brd, p2c-001.sch]
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2018-09-09 Fixed a very minor error of the schematic.
    [p2c-001.brd, p2c-001.sch]
2018-09-09 Trying MKR version of Pineapple IIc.
    [p2c-100.brd, p2c-100.sch]
2018-09-09 Test of MKR1000 version.
    [p2c-100.brd, p2c-100.sch]
2018-09-11 Renewed schematic. (Board layout and functions are not changed.)
    [p2c-001.brd, p2c-001.sch]
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2018-09-14 Document and pattern update.
    [p2c-001.brd, p2c-001.sch]
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2018-09-18 Changed small MIDI connector's name from MIDI to Alt.MIDI (ALTMIDI).
    [p2c-001.brd, p2c-001.sch]
2018-09-18 Printed version number: 1.3.0->1.3.1
    [p2c-001.brd]
2018-09-21 Modified silk size of D2, D7, D13 to 0.8mm. Removed silk pattern of PWR2. Updated HELP graphics.
    [p2c-001.brd, p2c-001.sch]
2018-09-21 Now Vin line has 18mil width.
    [p2c-001.brd, p2c-001.sch]
2018-09-24 Moved DC jack 1mm negative along Y axis.
    [p2c-001.brd, p2c-001.sch]
2018-09-24 Corner screws from M2 to M3.
    [p2c-001.brd, p2c-001.sch]
2018-09-24 Corner hole size from 3 to 2.8 (for M2.6 screws).
    [p2c-001.brd]
2018-09-25 Fixed power supply and pull-up of TLP552.
    [p2c-001.brd, p2c-001.sch]
2018-09-25 Changed pinnig of SW.
    [p2c-001.brd, p2c-001.sch]
2018-09-25 Autorouted. Perhaps needs some tweak.
    [p2c-001.brd]
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2018-09-26 Flipped ALTMIDI connector. Fixed silk pattern for Relay connector.
    [p2c-001.brd, p2c-001.sch]
2018-09-26 Fixed silk.
    [p2c-001.brd]
2018-10-29 Updated "help" pattern on the back side.
    [p2c-001.brd, p2c-001.sch]
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2020-02-17 hotfix/ pull-up of optocoupler.
    [p2c-001.brd, p2c-001.sch]
2020-02-18 Relay port 3p -> 2p.
    [p2c-001.brd, p2c-001.sch]
2020-02-18 Fixed typo (JST-SH).
    [p2c-001.brd]
2020-02-29 Pin 1 and 2 of MIDI IN are now connected to the power.
    [p2c-001.brd, p2c-001.sch]
2020-03-01 Selector of the power source (Regulated +5V and Arduino's Vcc).
    [p2c-001.brd, p2c-001.sch]
2020-03-23 Synchronise to Pineapple II.
    [p2c-001.brd, p2c-001.sch]
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2020-03-24 Changed pinout of Display port.
    [p2c-001.brd, p2c-001.sch]
2020-04-10 Added Diode for the reg.
    [p2c-001.brd, p2c-001.sch]
2020-04-10 Swapped DISP2 and DISP3 connected to SW.
    [p2c-001.brd, p2c-001.sch]
2020-04-12 Changed naming of components.
    [p2c-001.brd, p2c-001.sch]
2020-04-12 Fixed some naming.
    [p2c-001.sch]
2020-04-17 Swapped C1 and C2.
    [p2c-001.brd, p2c-001.sch]
2020-04-18 Fixed parameters of capacitors.
    [p2c-001.brd, p2c-001.sch]
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2020-04-18 Fixed orientation of capacitor.
    [p2c-001.brd]
2020-04-18 Added jumper for 5V operation of Qwiic.
    [p2c-001.brd, p2c-001.sch]
2020-04-18 Fixed type of diode.
    [p2c-001.brd, p2c-001.sch]
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2020-04-18 Added pad-n (cross mark) to the schematic.
    [p2c-001.sch]
2020-04-19 Now skips internal regulator.
    [p2c-001.brd, p2c-001.sch]
2020-04-19 Connected Vcc and AREF.
    [p2c-001.brd, p2c-001.sch]
2020-04-20 Fixed connection of SW1.
    [p2c-001.brd, p2c-001.sch]
2020-04-20 Fixed pinning of RN2.
    [p2c-001.brd, p2c-001.sch]
2020-04-20 Removed pull-up from DTCT pins.
    [p2c-001.brd, p2c-001.sch]
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2020-04-21 Moved the arrow slightly.
    [p2c-001.brd]
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2020-05-06 Fixed value of capacitor.
    [p2c-001.brd, p2c-001.sch]
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2020-05-07 Fixed capacitance (again).
    [p2c-001.brd, p2c-001.sch]
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2020-05-12 Added bogopins to connect the logicboard and the groveboard.
    [p2c-001.brd, p2c-001.sch, p2cgb-001.brd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]
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2020-05-13 Fixed connection of LED board.
    [p2cled-001.brd, p2cled-001.sch]
2020-05-16 Now the sensor output LED is connected to D11. (Following the new design of Pineapple II.)
    [p2c-001.brd, p2c-001.sch]
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2020-07-09 Swapped Vcc and Vcc/2.
    [p2c-001.brd, p2c-001.sch]
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2020-07-11 Fixed position of RTC connector.
    [p2c-001.brd]
2020-09-03 Fixed pinout of GPIO.
    [p2c-001.brd, p2c-001.sch]
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2021-11-09 Renamed signals for compatibility with Pineapple II 2.4.0 series.
    [p2c-001.brd, p2c-001.sch]
2021-11-09 Swapped RN1 and RN2.
    [p2c-001.brd, p2c-001.sch]
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2021-11-29 Flipped R10 and R11.
    [p2c-001.brd]
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2021-12-17 Fixed backside silk.
    [p2c-001.brd]

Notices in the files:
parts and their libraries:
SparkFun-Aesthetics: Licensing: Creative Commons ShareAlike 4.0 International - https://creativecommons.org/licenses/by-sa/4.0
